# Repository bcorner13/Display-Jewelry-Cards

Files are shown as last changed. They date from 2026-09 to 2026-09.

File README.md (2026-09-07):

# Display Jewelry Cards

Parametric countertop tiered display rack for 60×90mm earring cards, standing upright. One
tile holds a 3-column × 7-row grid of card slots on real discrete stepped tiers (a
staircase). Two tiles (same part, printed twice) form the full display, joined underneath
by a separate connector strip.

## Files

| File | Description |
|---|---|
| `Params.FCStd` | VarSet — all parametric variables |
| `Base.FCStd` | One tile: base block + 7-step staircase + 21 card slots + 2 bottom connector pockets |
| `ConnectorStrip.FCStd` | Bridging connector — capsule with a pin at each end |
| `Assembly.FCStd` | Assembly container for fit-checking two tiles + connector (not yet populated) |

## Status

Columns × rows and the connector interlock are both modeled and working (audit-clean,
verified by volume math and screenshots). Still open: populate `Assembly.FCStd` to verify
physical fit, then a test print to tune fit tolerances. See `intent.md` for open questions
and `plan.md` for the feature tree.

## Parametric usage

1. Open `Params.FCStd`, `Base.FCStd`, and `ConnectorStrip.FCStd` together in FreeCAD 1.1+
   (`Base` and `ConnectorStrip` both cross-reference `Params` via
   `<<Params>>#VarSet.VarName` expressions).
2. Edit `VarSet` in `Params.FCStd` — e.g. `NumColumns`, `RowCount`, `RowPitch`.
3. Recompute.

Key parameters (`Params.FCStd`):
- `Width`/`Depth` — tile footprint, mm (`Width` is **derived** from `NumColumns`/
  `SlotWidth`/`SlotSpacing`, not independent — 198.6 × 150)
- `LowerBackHeight`/`BackHeight` — base block height / ramp rise, mm (15 / 30)
- `SlotWidth`/`SlotHeight`/`SlotDepth` — one card slot's dimensions, mm (60.2 / 2 / 10)
- `NumColumns`/`RowPitch`/`RowCount` — pattern controls (3 / 35 / 7)
- `Connector*` — bridging-connector geometry and print-fit clearance, shared between
  `Base.FCStd`'s bottom pockets and `ConnectorStrip.FCStd`'s pins
- `SnapTab*` — parked, unused (earlier interlock attempt, superseded by the connector strip)

## Before committing

```bash
python3 scripts/audit_parametric.py
```

Must be clean before any commit. **Note:** the audit script doesn't catch every parametric
gap in this project (bare `AttachmentOffset` literals, unwired pattern `Occurrences`, a
VarSet property drifting from a formula used elsewhere) — see `CLAUDE.md` hard rule 1 for
the full list and how to check manually.

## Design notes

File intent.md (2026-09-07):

# Intent

## Goal

A countertop tiered display rack for 60×90mm earring cards, standing upright long-ways on
their short (60mm) edge. Rows are **actual discrete stepped tiers** — a real staircase, each
row its own physical step (Bradley's redesign, 2026-09-07) — not cuts into one continuous
ramp. Built and working as of 2026-09-07: **3 columns × 7 rows** (21 card slots, one tile).

Built as **two identical tiles** (same part printed twice) rather than one wide plate, for
transport. **Interlock: a separate connector strip** (`ConnectorStrip.FCStd`) — a
capsule-shaped bridge with a pin at each end, seating in matching pockets on each tile's
bottom — **2 connector pockets per side** (4 total, front+back pair on each edge, for
torsional rigidity — confirmed 2026-09-07), so any tile, leftmost/middle/rightmost, is the
same part. This supersedes the earlier snap-tab-built-into-the-tile idea, which Bradley
determined wouldn't hold well enough and removed (2026-09-06). Both the connector's
geometry and the tile's receiving pockets are done and audit-clean, built to sit flush with
the tile's bottom surface (a real tangent-vs-overlap gap bug was found and fixed here —
see `CLAUDE.md` hard rule 11).

## Constraints

* Must follow `CAD_STANDARDS.md` (mm units, manifold geometry, centered on the print bed,
  $36–$45 price target, 2.0–3.0mm default wall thickness, Silk-filament-friendly aesthetic).
* Printable without supports.
* Countertop use — freestanding, not wall-mounted.
* Card: 60mm wide (short edge, rests in the slot) × 90mm tall (standing height, "long ways"
  upright). **Fixed — not a design variable.**
* Column gap, row/column counts, tier geometry, tile width, and margins are the
  **adjustable levers** — make the layout work around the fixed 60×90mm card.
* `SlotWidth`=60.2mm (60mm card + 0.2mm clearance) — set.
* `Width` (tile footprint width) is now **derived** from `NumColumns*(SlotWidth+
  2*SlotSpacing)` = 198.6mm, not an independent value — keeps the footprint and the
  ramp/pocket extrusions from drifting apart (this had happened: a 1.4mm silent mismatch,
  fixed 2026-09-07).
* Connector: 40mm-long capsule, 5mm-radius pins 30mm apart, sits flush with the tile
  bottom via a stepped (deep round + shallow rectangular) pocket. `ConnectorClearance`=
  0.2mm/side — a first-pass estimate, tune after a test print/fit-check.

## Open questions (need Bradley's input)

* **Row pitch (`RowPitch`=35mm) and the row `Mode=Extent` setup** — working and verified by
  volume math, but the exact spacing values were chosen to fit the geometry rather than
  from an explicit ergonomic/aesthetic target. Worth a visual check once printed.
* **Wall/end margins** — how much material stays outside the outermost card column on each
  tile edge (currently whatever falls out of the `NumColumns`/`SlotWidth`/`SlotSpacing`
  math, not independently set).
* **Connector fit** — `ConnectorClearance`=0.2mm is unverified against an actual print;
  standard first-pass estimate per the project's material-dependent tuning convention (PLA
  vs. ASA shrink rates differ).
* **`Assembly.FCStd`** — populated 2026-09-07: two tiles + two connectors, geometrically
  verified (0mm³ interference on all 4 pin/pocket pairs, edge-to-edge tile alignment). Not
  joint-solved, just fixed links — good enough to demonstrate and geometrically confirm the
  fit; a physical test print is still the real verification.
* Any branding/engraving on the base, per the Silk-filament aesthetic guidance in
  `CAD_STANDARDS.md`?

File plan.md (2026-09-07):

# Plan — Display Jewelry Cards

**Status: DRAFT — core geometry done, verification pending.** Row/column layout (3×7,
discrete stepped tiers) and the connector-strip interlock are both modeled and audit-clean.
Remaining work is verification (print test, assembly fit-check) and cosmetic finishing.

---

## PARAMETERS

See `CLAUDE.md`'s "Params variables" table for the full current list (grouped: Base
geometry, Shelf/slot, Pattern, Connector, Snap-tab-parked). All bound, audit clean as of
2026-09-07.

---

## Row/column layout — done

3 columns × 7 rows (21 slots), built as **real discrete stepped tiers**:
- `LinearPattern001` repeats the shelf notch itself 7× along the ramp (`Mode=Extent`,
  `Offset=Depth`) — creates 7 actual physical steps.
- `RowPattern` repeats the card slot 7× to match (`Mode=Extent`, `Offset=RowPitch`),
  chained onto the column pattern's tip.
- Verified by volume math (exact match) and visually (screenshot: 7 clean steps, 3 slot
  grooves each).
- See `CLAUDE.md` hard rules 3, 6, 7 for the debugging history (sign-convention bug,
  stuck-object NULL-shape bug, `ObjectXZ`-retrofit unreliability) — worth reading before
  touching this part of the tree again.

## Connector-strip interlock — done

Replaces the rejected snap-tab (see `intent.md`). `ConnectorStrip.FCStd`: capsule bridge,
pin at each end (`ConnectorPinSpan`=30mm apart, `ConnectorRadius`=5mm,
`ConnectorPinHeight`=5mm, chamfered). `Base.FCStd`: **2 pairs of "keyhole" pockets per
side** (4 total — Bradley wanted 2 per side for torsional rigidity), each pair a deep round
pin hole + shallow rectangular plate recess for a flush fit, 15mm inset (`ConnectorInset`)
from each tile edge, symmetric front/back about `Y=0` via `ConnectorPairOffset`(50mm) — so
any tile works as leftmost/middle/rightmost. Verified by volume diff (exact match to the
computed expected value, 2nd pair an exact 2× multiple of the 1st) and visually
(bottom-view screenshot: 4 clean gap-free pockets).

**Fixed a real bug post-first-pass:** the plate recess was originally built tangent to the
pin hole's *edge*, not overlapping it — left an uncut crescent-shaped sliver everywhere
except the single tangent point (looked like a visible gap in a render, confirmed by
point-containment test). Fixed by starting the rectangle at the pin's *center* X instead —
see `CLAUDE.md` hard rule 11.

**Also hit a live data-loss incident**: all 7 `Connector*` Params vanished mid-session
(from both the live document and disk) while everything else survived — see `CLAUDE.md`
hard rule 10 for the symptom (expressions silently frozen, error only in Report View) and
recovery (re-add the same properties; downstream expressions re-resolve automatically).

---

## FEATURE TREE (current state)

1-6: Base block, ramp, shelf notch (patterned ×7 as steps), card slot (patterned ×3
    columns ×7 rows = 21). **Done** — see `CLAUDE.md` Assembly architecture for the exact
    object names/chain.
7. Connector pockets, **2 pairs per side** (front + back, torsional rigidity). **Done.**
8. Populate `Assembly.FCStd` — two tile `App::Link`s + two `ConnectorStrip` `App::Link`s
   (front/back seam pair). **Done** (2026-09-07) — plain fixed-`Placement` links, not
   solved joints, but positioned by the same math as the pocket geometry and verified by
   Boolean intersection (0mm³ interference on all 4 pin/pocket pairs) — see `CLAUDE.md`.
9. Fillet/chamfer slot mouths and step edges per `CAD_STANDARDS.md` aesthetic guidance
   (avoid sharp overhangs for Silk filament).
10. Test print (PLA first, per project convention) — verify `SlotHeight`/`SlotWidth`/
    `ConnectorClearance` actually fit real cards and the real connector before treating
    them as final.
11. Export STL/3MF to `stl/`/`3mf/` — one tile file + one connector file (each tile uses
    the same STL, printed twice).

---

## VALIDATION

* `python3 scripts/audit_parametric.py` must report 0 issues. **Currently clean across all
  4 project files.** Remember what it doesn't catch — see `CLAUDE.md` hard rule 1.
* `validate_document()`/`validate_object()` after any structural change (ignore the sketch
  "non-positive volume" false positive — hard rule 9).
* For any new Pocket: verify cut direction/volume by diffing `Shape.Volume` before/after.
* Bounding box must fit the Creality K2 Plus / ELEGOO Saturn 4 print volumes — the
  120×140mm figure in `CAD_STANDARDS.md` doesn't apply to this design's tiling; verify
  against real bed specs before finalizing tile size.
* **Assembly fit-check — done** (2026-09-07): `Assembly.FCStd` has two tiles + two
  connectors positioned via the same X/Y math as the pocket geometry; confirmed 0mm³
  Boolean interference on all 4 pin/pocket pairs and edge-to-edge tile alignment (no gap,
  no overlap). Not joint-solved (plain fixed links) — sufficient for a geometric fit-check,
  not a substitute for the physical print-verify step below.
* Print-verify: one test print in PLA before committing to `SlotHeight`/`SlotWidth`/
  `RowPitch`/`ConnectorClearance` final values.

---

## Execution gate

Per `PROJECT_BOOTSTRAP.md`: execution proceeds via Bradley's live iteration in FreeCAD, with
each change verified (audit + `validate_document` + volume/geometry checks) and recorded
here as it happens — this plan tracks and formalizes that work rather than gating it ahead
of time.

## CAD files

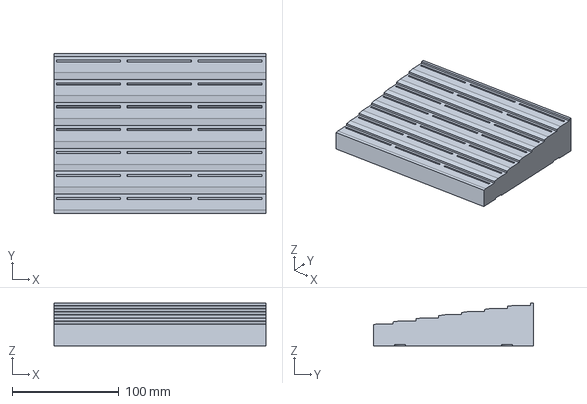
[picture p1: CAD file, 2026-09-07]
Base.FCStd
198.6 x 150.0 x 40.0 mm

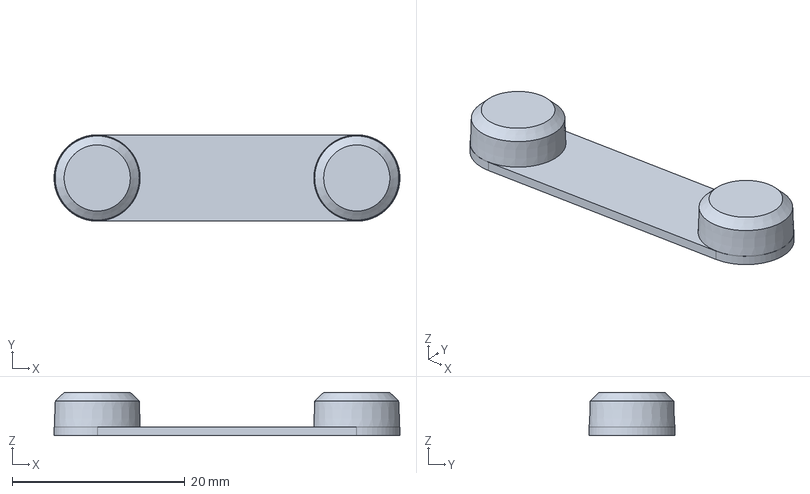
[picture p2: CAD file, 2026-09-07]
ConnectorStrip.FCStd
40.0 x 10.0 x 5.00 mm

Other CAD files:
Assembly.FCStd
Params.FCStd

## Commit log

2026-09-06 Bootstrap Display Jewelry Cards project per PROJECT_BOOTSTRAP.md
    - Standard folder structure (3mf/ stl/ gcode/ images/ macros/ scripts/)
    - CAD_STANDARDS.md, MCP_TOOLS_REFERENCE.md, tools.md copied verbatim from
    Commercial License root
    - CLAUDE.md filled from CLAUDE_TEMPLATE.md, documenting the existing
    Base.FCStd/Params.FCStd geometry (verified via MCP + on-disk XML, not
    guessed)
    - scripts/audit_parametric.py: started from the Clocks-corrected version
    (fixed DIMENSIONAL_TYPES enum) and fixed a second bug found here — the
    DAG-risk regex matched past an empty AttachmentSupport into an unrelated
    ExternalGeometry Link, producing a false positive on Sketch001
    - .claude/settings.json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
    [Base.FCStd, Params.FCStd]
2026-09-06 Bind Sketch001's remaining unbound dimension to a new BackHeight Param
    Bradley added BackHeight (30mm) to Params.FCStd and bound
    Sketch001.Constraints[4] to it directly in FreeCAD. Verified live via MCP
    and confirmed with the corrected audit script: down to 1 remaining
    finding (Pad.Length, still an unbound literal). Docs (CLAUDE.md, plan.md,
    intent.md) updated to match; model files re-saved from the live session.
    Claude-Session: https://claude.ai/code/session_012jTKCAzSzuHhfxeMsttHjP
    [Base.FCStd, Params.FCStd]
2026-09-06 Bind Pad.Length to a dedicated LowerBackHeight Param, not Depth
    Bradley split this himself: the earlier fix had bound Pad.Length to the
    existing Depth variable (150mm), which conflated the base rectangle's
    Y-footprint with the block's Z-height and silently changed the base
    height 50mm->150mm as a side effect. Corrected to a new dedicated
    LowerBackHeight variable (50mm), restoring the original height with its
    own concept-specific Param per hard rule 5 (one knob, one concern).
    Verified live via MCP: audit_parametric.py now reports 0 issues project-
    wide. Docs (CLAUDE.md, plan.md, intent.md) updated to match; model files
    re-saved from the live session.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
    [Base.FCStd, Params.FCStd]
2026-09-06 Confirm product spec: 5x4 tiered card grid, two-tile split; drop sample card
    Bradley confirmed the real design intent and made two live edits this
    session:
    - Card size fixed: 60x90mm earring cards, standing upright long-ways
    (90mm tall). Card dimensions are not a design variable; layout (column
    count/gap, row count, tier offsets, tile split) adjusts around them.
    - Grid: 5 columns x 4 rows, rows tiered/cascading (theater-seating style),
    matching the angled-backrest shelf already modeled.
    - Width changed 420mm -> 210mm: the full 5-column, 420mm-wide row is now
    built as two mirror-symmetric ~210mm half-tiles split through the center
    column, to keep each printed piece transportable. T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
    [Base.FCStd, Params.FCStd]
2026-09-06 Fix Shelf/Slot attachment, add row pattern, wire up NumColumns
    Bradley rejected the snap-tab interlock (won't hold the tiles together)
    and removed it live in FreeCAD, then built a first pass at the top row
    of card slots (Shelf/Slot sketches, column LinearPattern) himself,
    trying to keep it parametric. Picked up from there:
    Fixed (both silent gaps audit_parametric.py doesn't check):
    - Sketch003 ("Shelf")'s AttachmentSupport had gone empty -- MapMode said
    FlatFace but nothing backed it, so it was frozen at a stale Placement
    and would NOT track BackHeight. Rebuilt on the same flat, non-rotated
    plane as SideProfile, with geometry computed directly from the ramp's
    own line equation (Yb/Z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
    [Base.FCStd, Params.FCStd]
2026-09-07 Fix Width drift, verify row/column redesign, add connector-strip interlock
    Bradley finished the row/column layout himself (redesigned it into real
    discrete stepped tiers -- 3 columns x 7 rows -- rather than the
    continuous-ramp approach I'd been debugging), removed the rejected
    snap-tab interlock, and created ConnectorStrip.FCStd: a separate
    capsule-shaped bridging connector with a pin at each end. Picked up from
    there:
    Found and fixed (the "one setting you might be missing"):
    - Width was an independent stored VarSet value (200mm) while BoxFooter's
    own footprint constraint had been changed to a derived formula
    (NumColumns*(SlotWidth+2*SlotSpacing) = 198.6mm) -- a silent 1.4mm
    mismatch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
    [Assembly.FCStd, Base.FCStd, ConnectorStrip.FCStd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]
2026-09-07 Fix connector plate-recess gap, add 2nd pocket pair per side, recover lost Connector Params
    Bradley caught a real geometric bug from a screenshot: the rectangular
    plate recess was only tangent to the round pin hole (touching at one
    point, not overlapping), leaving an uncut crescent-shaped sliver of
    material between them everywhere except that single point. Fixed by
    starting each rectangle at the pin's center X instead of its edge --
    guarantees full overlap regardless of curvature. Confirmed by a
    point-containment test on the former gap location and a fresh
    screenshot.
    While diagnosing why the expression edit wasn't taking effect,
    discovered all 7 Connector* VarSet properties had vanished fr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
    [Base.FCStd, ConnectorStrip.FCStd, Params.FCStd]
2026-09-07 Populate Assembly.FCStd: two-tile fit-check demo, verified interference-free
    Bradley asked to demonstrate two stands with two connectors. Populated
    Assembly.FCStd with 4 App::Link objects (not joint-solved -- plain
    fixed placements, positioned by the same X/Y math the pocket/connector
    geometry itself uses, not eyeballed):
    - TileA/TileB: two Base#Body links, TileB offset by exactly Width along
    X so the tiles sit edge-to-edge with no gap or overlap.
    - ConnectorFront/ConnectorBack: two ConnectorStrip#Body links at the
    seam X, at each pocket pair's Y (+/-ConnectorPairOffset), Z=0.
    Verified geometrically, not just visually: Boolean intersection between
    each tile and each connector returns e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
    [Assembly.FCStd, Base.FCStd, ConnectorStrip.FCStd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]
